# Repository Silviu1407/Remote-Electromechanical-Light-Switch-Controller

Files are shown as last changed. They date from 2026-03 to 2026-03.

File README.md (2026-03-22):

# 💡 Remote Electromechanical Light Switch Controller

## 📌 Overview
This project is a custom electromechanical device designed to remotely control standard dorm room light switches. Built using an Arduino Nano, 3D-printed components, and servomotors, the system allows you to turn room lights on and off via an IR remote. 

A key feature of this project is its **motorized lift mechanism**. When the system is not in use, it can be mechanically lifted away from the wall switches, allowing them to be operated manually without interference. 

## ⚙️ Hardware Components
* **Microcontroller:** Arduino NANO
* **Actuators (Switches):** 3x 180° Servomotors 
* **Actuators (Lift Mechanism):** 2x Continuous Rotation (360°) Servomotors
* **Sensors:** IR Receiver
* **Power Supply:** 5V / 3A Dual-Port Charger (Powers both the board and the servos)
* **Other:** Capacitor (for voltage stabilization), jumper wires, custom 3D-printed mechanical parts.

## 🚀 Features & Functionality
* **Individual Light Control:** Buttons `1`, `2`, and `3` on the IR remote toggle their respective light switches using the 180° servos.
* **Lift Mechanism:** Pressing the `UP` arrow raises the entire assembly off the switches, restoring manual access. Pressing the `DOWN` arrow lowers it back into the operational position.
* **Safety Limits:** The code includes bounds checking. If the system is already lifted, it will ignore further `UP` commands to prevent mechanical damage (and vice versa for the `DOWN` command).
* **Safety Lock:** The servos responsible for switching the lights are disabled while the system is in the lifted position.

## 💻 Software Implementation
This repository contains two different software approaches for educational and performance-testing purposes:

### 1. The "Library" Version (`C++` with standard Arduino libraries)
This version uses standard Arduino libraries (`<Servo.h>` and `<IRremote.hpp>`). 
* **Pros:** Easy to read, highly stable, and quick to implement. 
* **Note:** The lift servos are mapped to analog pins (`A0`, `A1`) to avoid hardware timer conflicts with the `Servo.h` library, which utilizes Timer 1.

### 2. The "Register" Version (`Bare-Metal C`)
This version achieves the same functionality using direct port manipulation and hardware registers instead of the `Servo.h` library.
* **Pros:** Deep dive into AVR architecture, fine-grained control over PWM signals, and optimized execution time.
* **Features:** Custom ADC initialization, manual PWM generation for the 180° servos, and a custom sequential PWM generation method for the continuous rotation lift servos to ensure perfect synchronization.

## 🔗 Simulation
You can view and interact with a simulation of the circuit and logic on Tinkercad:
[Tinkercad Simulation Link](https://www.tinkercad.com/things/3BcjFi1SrNA-intrerupator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)

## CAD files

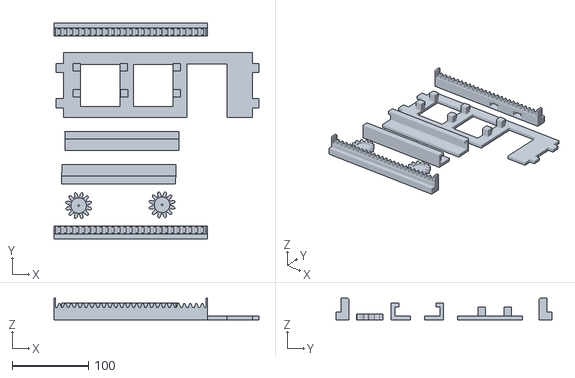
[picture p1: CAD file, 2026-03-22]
3D_printed_parts.stl
268.7 x 283.0 x 28.5

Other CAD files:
Light_Switch.dwg

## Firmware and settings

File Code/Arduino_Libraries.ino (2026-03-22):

#include <Servo.h>
#include <IRremote.hpp>

// --- PINI EXISTENTI (Servo 180) ---
const int SERVO_PIN_1 = 8;
const int SERVO_PIN_2 = 9;
const int SERVO_PIN_3 = 10;

// --- PINI NOI (LIFT - PE ANALOG!) ---
// Folosim A0 si A1 ca sa evitam conflictele cu Timer 0 si Timer 2
const int SERVO_LIFT_1_PIN = A0; 
const int SERVO_LIFT_2_PIN = A1; 

const int IR_PIN = 2;

// --- SETĂRI LIFT ---
const int DURATA_MISCARE = 3000; 
bool esteSus = false;

// --- POZIȚII ---
const int POS_LEFT   = 45;
const int POS_CENTER = 90;
const int POS_RIGHT  = 135;

const uint16_t CMD_BTN_1  = 0x45; 
const uint16_t CMD_BTN_2  = 0x46; 
const uint16_t CMD_BTN_3  = 0x47; 

uint8_t STARE_ANTERIOARA_1 = 0;
uint8_t STARE_ANTERIOARA_2 = 0;
uint8_t STARE_ANTERIOARA_3 = 0;

const uint16_t CMD_SAGEATA_SUS = 0x18; // Pune codul tau!
const uint16_t CMD_SAGEATA_JOS = 0x52; // Pune codul tau!

Servo myServo1, myServo2, myServo3;
Servo liftServo1, liftServo2;

const int DURATA_REVENIRE  = 750;

void setup() {
  Serial.begin(9600);
  
  // Atasare Servo 180
  myServo1.attach(SERVO_PIN_1);
  myServo2.attach(SERVO_PIN_2);
  myServo3.attach(SERVO_PIN_3);
  
  myServo1.write(POS_CENTER);
  myServo2.write(POS_CENTER);
  myServo3.write(POS_CENTER);

  // Atasare Lift (PE A0 si A1)
  liftServo1.attach(SERVO_LIFT_1_PIN);
  liftServo2.attach(SERVO_LIFT_2_PIN);

  // STOP INITIAL
  liftServo1.write(90);
  liftServo2.write(90);

  IrReceiver.begin(IR_PIN, ENABLE_LED_FEEDBACK);
  Serial.println("Sistem gata! Lift pe A0 si A1.");
}

void loop() {
  if (IrReceiver.decode()) {
    uint16_t cmd = IrReceiver.decodedIRData.command;
    if (cmd != 0) { Serial.print("Cod: 0x"); Serial.println(cmd, HEX); }

    // --- LIFT ---
    if (cmd == CMD_SAGEATA_SUS && !esteSus) {
        Serial.println(">> Urcam...");
        liftServo1.write(180);
        delay(100);          // Pauza antishoc
        liftServo2.write(0); // Sens opus
        delay(DURATA_MISCARE);
        liftServo1.write(90); liftServo2.write(90); // Stop
        esteSus = true;
    }
    else if (cmd == CMD_SAGEATA_JOS && esteSus) {
        Serial.println(">> Coboram...");
        liftServo1.write(0);
        delay(100);          // Pauza antishoc
        liftServo2.write(180);
        delay(DURATA_MISCARE);
        liftServo1.write(90); liftServo2.write(90); // Stop
        esteSus = false;
    }

    // --- SELECTIE & CONTROL 180 ---
    else if (cmd == CMD_BTN_1 && STARE_ANTERIOARA_1 == 0) 
    {
        myServo1.write(POS_LEFT);
        STARE_ANTERIOARA_1 = 1;
        delay(DURATA_REVENIRE);
        myServo1.write(POS_CENTER);
    }
    else if (cmd == CMD_BTN_1 && STARE_ANTERIOARA_1 == 1) 
    {
        myServo1.write(POS_RIGHT);
        STARE_ANTERIOARA_1 = 0;
        delay(DURATA_REVENIRE);
        myServo1.write(POS_CENTER);
    }

    else if (cmd == CMD_BTN_2 && STARE_ANTERIOARA_2 == 0)
    {
        myServo2.write(POS_RIGHT);
        STARE_ANTERIOARA_2 = 1;
        delay(DURATA_REVENIRE);
        myServo2.write(POS_CENTER);
    }
    else if (cmd == CMD_BTN_2 && STARE_ANTERIOARA_2 == 1)
    {
      myServo2.write(POS_LEFT);
      STARE_ANTERIOARA_2 = 0;
      delay(DURATA_REVENIRE);
      myServo2.write(POS_CENTER);
    }

    else if (cmd == CMD_BTN_3 && STARE_ANTERIOARA_3 == 0)
    {
        myServo3.write(POS_LEFT);
        STARE_ANTERIOARA_3 = 1;
        delay(DURATA_REVENIRE);
        myServo3.write(POS_CENTER);
    }
    else if (cmd == CMD_BTN_3 && STARE_ANTERIOARA_3 == 1)
    {
      myServo3.write(POS_RIGHT);
      STARE_ANTERIOARA_3 = 0;
      delay(DURATA_REVENIRE);
      myServo3.write(POS_CENTER);
    }

    IrReceiver.resume();
  }
}

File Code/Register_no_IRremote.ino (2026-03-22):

#include <avr/io.h>
#include <avr/interrupt.h>
#include <util/delay.h>

// ================= CONFIGURARE HARDWARE =================
// Servo 1: PIN 8  (PORTB, Bit 0)
// Servo 2: PIN 9  (PORTB, Bit 1)
// Servo 3: PIN 10 (PORTB, Bit 2)
// Lift 1:  PIN A0 (PORTC, Bit 0)
// Lift 2:  PIN A1 (PORTC, Bit 1)
// IR Recv: PIN 2  (INT0)
// ADC In:  PIN A5 (Neconectat - folosit doar pentru cerinta ADC)

// --- CODURI TELECOMANDA (Completeaza cu ce vezi in Serial Monitor!) ---
uint32_t CMD_BTN_1       = 0xFFA25D; 
uint32_t CMD_BTN_2       = 0xFF629D; 
uint32_t CMD_BTN_3       = 0xFFE21D; 
uint32_t CMD_SAGEATA_SUS = 0xFF18E7; 
uint32_t CMD_SAGEATA_JOS = 0xFF4AB5; 

// --- CONFIGURARI TIMP & POZITII (Ce ai stabilit ca merge bine) ---
const long DURATA_LIFT = 3000; 

// Calibrare Servo 180 (Ajustata la Stanga cum ai vrut)
const int POS_US_LEFT   = 400;   // Maxim Stanga (aprox 0 grade)
const int POS_US_CENTER = 900;  // Centru (90 grade)
const int POS_US_RIGHT  = 1400;  // Maxim Dreapta (aprox 180 grade) 

// --- VARIABILE STARE ---
uint8_t stare_1 = 0; 
uint8_t stare_2 = 0;
uint8_t stare_3 = 0;
int esteSus = 0;

// --- VARIABILE DECODOR IR MANUAL ---
volatile uint32_t ir_code = 0;      
volatile bool     ir_ready = false; 
volatile uint32_t last_ir_code = 0; 

// =========================================================================
// CAPITOLUL 3 & 2: TIMER1 si INTERRUPT (Decodor IR NEC)
// =========================================================================
void Timer1_Init() {
    // Timer 1 Normal Mode, Prescaler 64
    // 16MHz / 64 = 250kHz => 1 tick = 4 microsecunde
    TCCR1A = 0; 
    TCCR1B = (1 << CS11) | (1 << CS10); 
}

void INT0_Init() {
    // Configuram INT0 (Pin 2) sa declanseze la FALLING EDGE (cand semnalul cade)
    // EICRA: ISC01=1, ISC00=0
    EICRA |= (1 << ISC01); 
    EIMSK |= (1 << INT0); // Activare INT0
}

// Aceasta functie ruleaza AUTOMAT cand senzorul IR primeste semnal
ISR(INT0_vect) {
    static uint16_t last_timer_val = 0;
    static int8_t   bit_count = -1; 
    
    uint16_t current_time = TCNT1;
    uint16_t diff = current_time - last_timer_val; // Durata de la ultimul puls
    last_timer_val = current_time;

    // Protocol NEC:
    // START Bit: ~13.5ms (13500us). Ticks: 13500 / 4 = 3375
    // Marja eroare: 3000 - 3600
    if (diff > 3000 && diff < 3600) {
        bit_count = 0;
        ir_code = 0;
        return;
    }

    // Citire Biti de date (0 sau 1)
    if (bit_count >= 0 && bit_count < 32) {
        // Ignoram zgomotul foarte scurt (< 600us)
        if (diff > 150) { 
            ir_code <<= 1; // Facem loc pentru bitul nou
            
            // Bit '1': ~2.25ms (2250us / 4 = 562 ticks)
            // Bit '0': ~1.12ms (1120us / 4 = 280 ticks)
            // Prag de separare: 400 ticks
            if (diff > 400) {
                ir_code |= 1; // E un 1
            }
            // Altfel e 0

            bit_count++;
            
            // Am primit toti cei 32 de biti?
            if (bit_count == 32) {
                last_ir_code = ir_code;
                ir_ready = true;
                bit_count = -1; // Reset pt urmatoarea tura
            }
        }
    }
}

// =========================================================================
// CAPITOLUL 5: ADC (Citire Analogica prin Registri)
// =========================================================================
void ADC_Init() {
    // Referinta AVcc, Prescaler 128
    ADMUX = (1 << REFS0);
    ADCSRA = (1 << ADEN) | (1 << ADPS2) | (1 << ADPS1) | (1 << ADPS0);
}

uint16_t ADC_Read(uint8_t channel) {
    ADMUX = (ADMUX & 0xF0) | (channel & 0x07); // Selectare canal
    ADCSRA |= (1 << ADSC); // Start Conversie
    while(ADCSRA & (1 << ADSC)); // Asteptare final
    return ADC;
}

// =========================================================================
// CAPITOLUL 4 & 6: PWM Software si Serial (Functiile tale)
// =========================================================================

void misca_servo_manual(uint8_t servo_id, int pulse_width_us, int durata_ms) {
    long cycles = durata_ms / 20; 
    for (int i = 0; i < cycles; i++) {
        if (servo_id == 1)      PORTB |= (1 << PB0);
        else if (servo_id == 2) PORTB |= (1 << PB1);
        else if (servo_id == 3) PORTB |= (1 << PB2);

        for(int k=0; k < pulse_width_us; k+=10) _delay_us(10); 

        if (servo_id == 1)      PORTB &= ~(1 << PB0);
        else if (servo_id == 2) PORTB &= ~(1 << PB1);
        else if (servo_id == 3) PORTB &= ~(1 << PB2);

        int pauza = 20000 - pulse_width_us;
        for(int k=0; k < pauza; k+=100) _delay_us(100);
    }
}

void misca_lift_simultan(int pulse1, int durata_ms) {
    long cycles = durata_ms / 20;
    for (int i = 0; i < cycles; i++) {
        PORTC |= (1 << PC0);
        PORTC |= (1 << PC1);
        for(int k=0; k < pulse1; k+=10) _delay_us(10);
        PORTC &= ~(1 << PC0);
        PORTC &= ~(1 << PC1);

        int timp_consumat = pulse1;
        if (timp_consumat < 20000) {
            for(int k=0; k < (20000 - timp_consumat); k+=100) _delay_us(100);
        } else { _delay_us(100); }
    }
}

// ================= SETUP si LOOP =================

void setup() {
    Serial.begin(9600);

    // 1. Configurare Porturi (I/O)
    DDRB |= (1 << PB0) | (1 << PB1) | (1 << PB2); // Iesiri Servo
    DDRC |= (1 << PC0) | (1 << PC1);             // Iesiri Lift
    DDRD &= ~(1 << PD2); // Intrare IR
    PORTD |= (1 << PD2); // Pull-up intern

    // 2. Initializare Module
    ADC_Init();
    Timer1_Init();
    INT0_Init();
    
    // 3. Activare Intreruperi
    sei(); 

    Serial.println("Sistem Gata. Mod: LOW LEVEL (Fara Librarii).");
    Serial.println("Apasa butoanele pentru a vedea codurile!");

    // Pozitii initiale
    misca_servo_manual(1, POS_US_CENTER, 300);
    misca_servo_manual(2, POS_US_CENTER, 300);
    misca_servo_manual(3, POS_US_CENTER, 300);
    misca_lift_simultan(1500, 300);
}
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
